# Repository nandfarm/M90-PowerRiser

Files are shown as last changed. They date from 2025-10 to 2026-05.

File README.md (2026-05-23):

# M90-PowerRiser
PowerRiser – NVMe 2230 and 2242 Expansion board for Lenovo Tiny 6 Series M90q Gen 1 and 2 and P340 and P350

# Buy preassembled boards:

Best for European locations (EUR currency): </br>


Best for International locations (USD currency): </br>


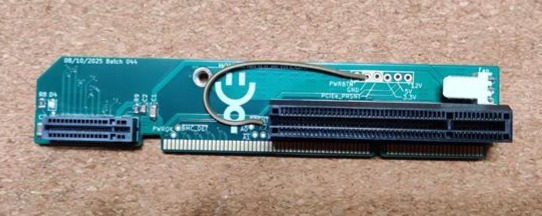
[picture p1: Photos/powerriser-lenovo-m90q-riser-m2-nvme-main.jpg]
Main photo of the board


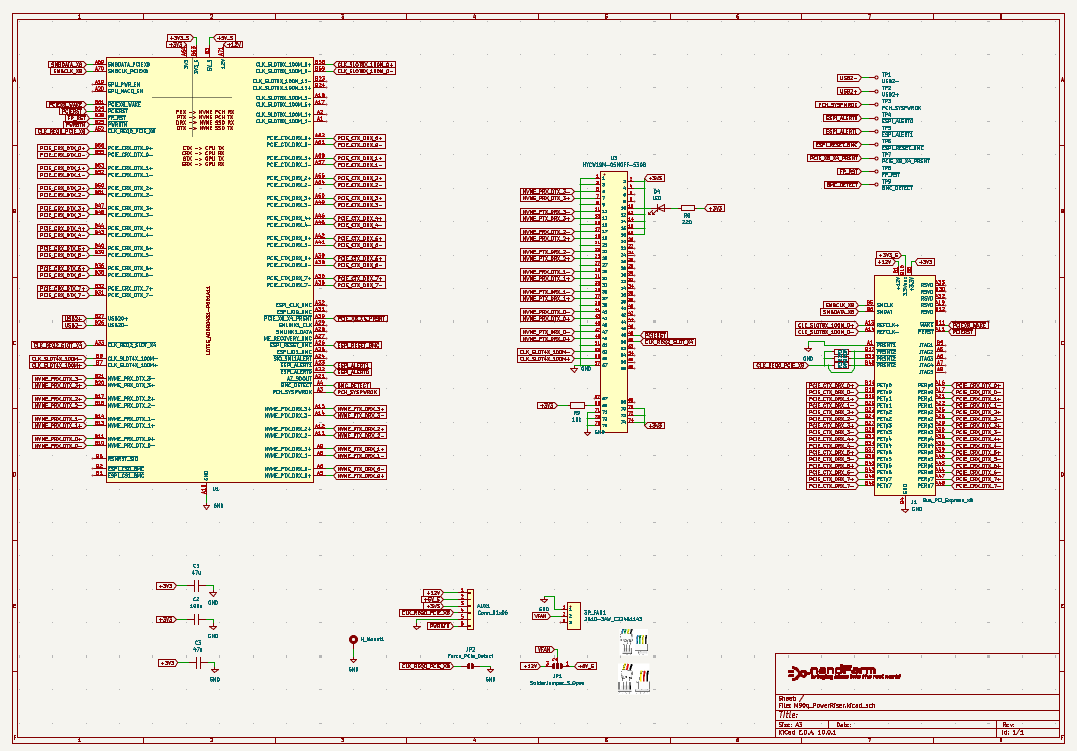
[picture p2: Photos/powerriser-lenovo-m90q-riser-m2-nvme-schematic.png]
Schematic of the board


This is the first ~UNTESTED~ TESTED version of the M90 PowerRiser. Like the previous one it is a custom-designed passive riser board that allows you to break out the proprietary Lenovo Tiny 6 series PCIe connector into a standard open-ended x8 PCIe slot, while also providing an additional M.2 NVMe slot for further storage expansion. This board was specifically designed for select Lenovo Tiny 6 series systems (10th/11th gen), such as:

- ThinkCentre M90q Gen 1 and Gen 2

- ThinkStation P340 Tiny

- ThinkStation P350 Tiny

These boards are compatible with the following Lenovo riser FRU code: 5C50W00877. Basically, this riser will do the same job and will allow you access to an extra 4-lane NVMe M.2 slot, supporting all NVMe M.2 form factors, at PCIe 3.0 speeds.

⚠ Please note: The additional M.2 slot supports only PCIe NVMe drives, not SATA drives.

## Prototype Updates (01/12/2025)

Ok some updates are required. 

The first prototype boards have arrived and I could not wait to solder one to test it. 

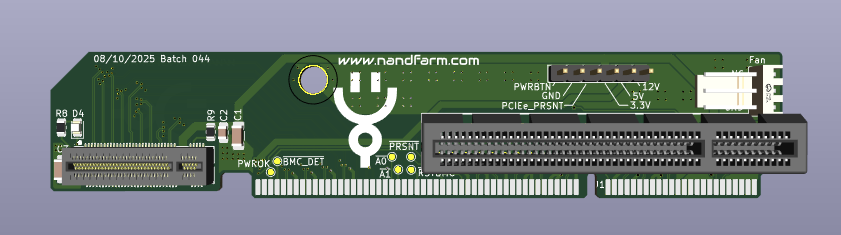
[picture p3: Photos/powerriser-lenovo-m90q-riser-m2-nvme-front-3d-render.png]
Top render of the board


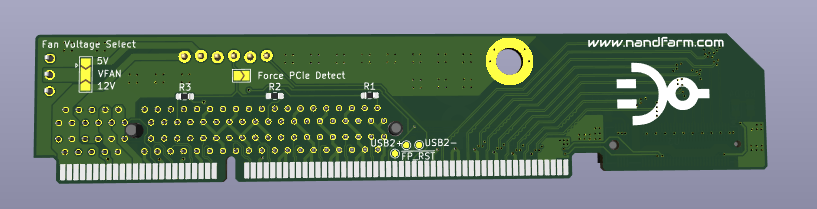
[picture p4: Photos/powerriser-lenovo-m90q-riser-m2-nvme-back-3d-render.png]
Bottom render of the board


~Issue no 1: It appears that the chassy has different folds than the m720q family of devices and the pertruding pins of the FAN connector on the bottom side of the board touch the chassy. This is a problem since no one wants a short so the fan header needs to move somewhere else or, find a surface mount version.~

Issue no 1: Has been solved by moving the connector and rotating it 180 degrees. 

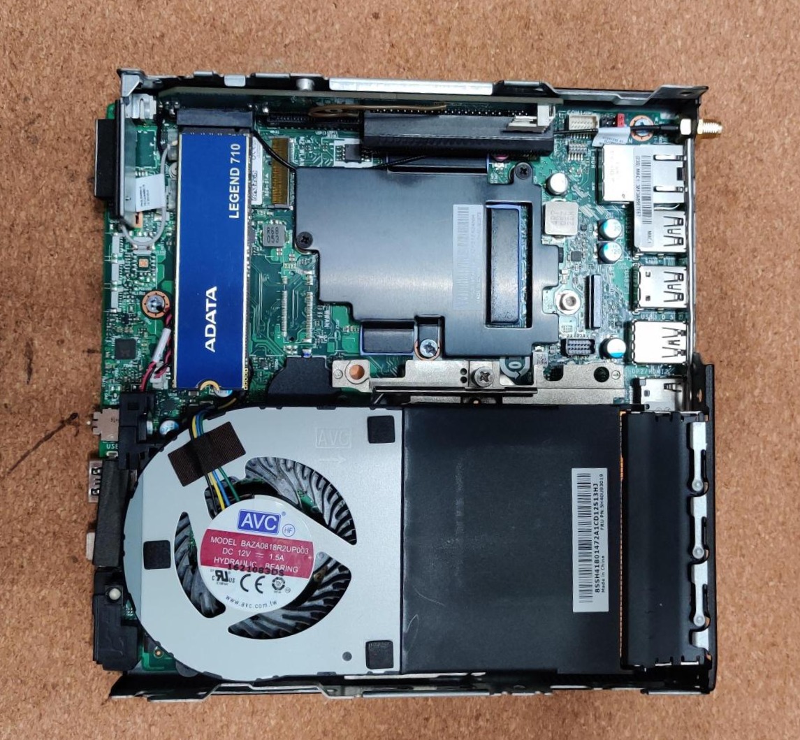
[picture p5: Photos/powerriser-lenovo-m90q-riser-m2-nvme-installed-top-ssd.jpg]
Top view of installed board


~Issue no 2: I have routed some of the low speed # detect wires poorly and the board was not initially detected by the device. After some adjustments with a box cutter and the soldering iron, the M90q detects both the PCIe PERC and the NVMe SSD. This needs to be corrected in the next hardware version.~

Issue no 2: Has been solved in the latest revision.

~Potential issue no 3: The M90q detects (lspci on Ubuntu) the NVMe but downgrades it to PCIe gen 3 (not 4) (LnkCap says PCIe4 capable and LnkSta says PCIe3 (Downgrade)). R/W speeds are matching PCIe gen 3 speeds and are stable. Not sure if the Tiny is not capable of PCIe gen 4 or there is somethign wrong with my board. The high speed trace impedances have been tested on a signal analyzer and are within spec. Did not find a way to force PCIe gen 4 speeds on the device yet. Will keep investigating.~

Potential issue no 3: Apparently this is normal behaviour as the PCH of this generation of boards is only PCIe 3.0 compatible. So the NVMe SSDs connected to this slot will run at 3.0 speeds and not at 4.0 like the ones on the motherboard. 

---------------------------------------
Other things: 

- There is no way to put the NVMe connector on the side of the riser like the m720q version of the riser since there is no space to place even the 2230 sized NVMe. The good news by putting this vertically on the riser, you can now insert 2280 sized SSDs without space constraints. The bad news is that the vertical M.2 slot can not be sourced easily/cheaply so would add an extra assembly step.
- The position of the M.2 slot is perfectly placed to clear the wifi/BT card and to have the posibility to add a longer card on the x8 PCIe slot AS LONG AS there is nothing under the PCIe board and there is no heatsink on the NVMe. (excuse the bothced fan added to the PERC card :D )
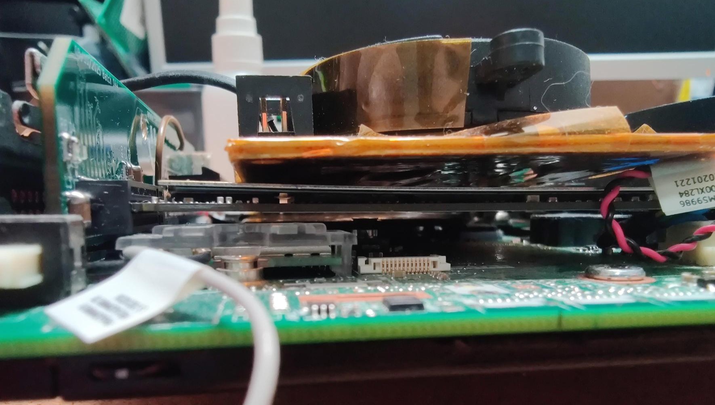
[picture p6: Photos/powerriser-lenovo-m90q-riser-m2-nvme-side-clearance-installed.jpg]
Side view of clearance of the board
  
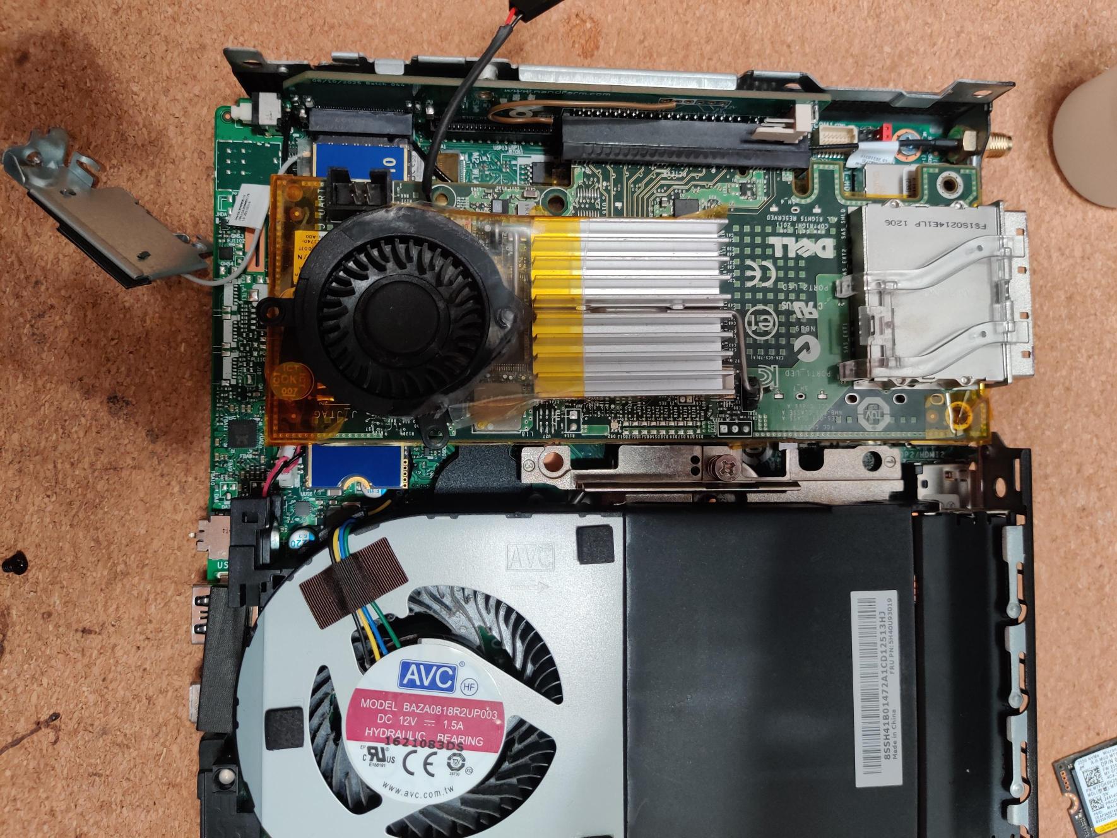
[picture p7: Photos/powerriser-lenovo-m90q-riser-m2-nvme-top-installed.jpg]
Top view of clearence of the board
  
- There seems to be a way to bifurcate the x8 connection in two x4 onnectors without any hardware modiffication on the motherboard. Have to explore this further since this could lead to the ability to connect up to 5 NVMes in one tiny device. Would be great for a NAS with RAID 5.
- 
  ↑ There is and the new board is under test. Will release once it has been thoroughly tested.
- Have to see if the USB2 port is host or device as it could be interesting for those who want to add something extra like a fan speed controller.
- 
  ↑ Will not be implemented in the current version.

I think there is value in creating this riser as it has some cool advantages: 
- you have the space for a 2280 sized SSD
- selectable fan voltage can work at 12v or 5v
- there is the posibility of bifurcation of the x8 pcie without hardware modiffications (imagine 5 NVMes on this machine -> RAID 5 NAS *drooling*)
- extra USB2 connection (not sure if device or host yet) 
- SPI connection to the PCH (have to explore this more in depth)
- no need for clock buffer/divider as the device now breaks out 4x 100MHz clock sources
- there are connections for the power and reset button that could be used if a custom chassy is made.

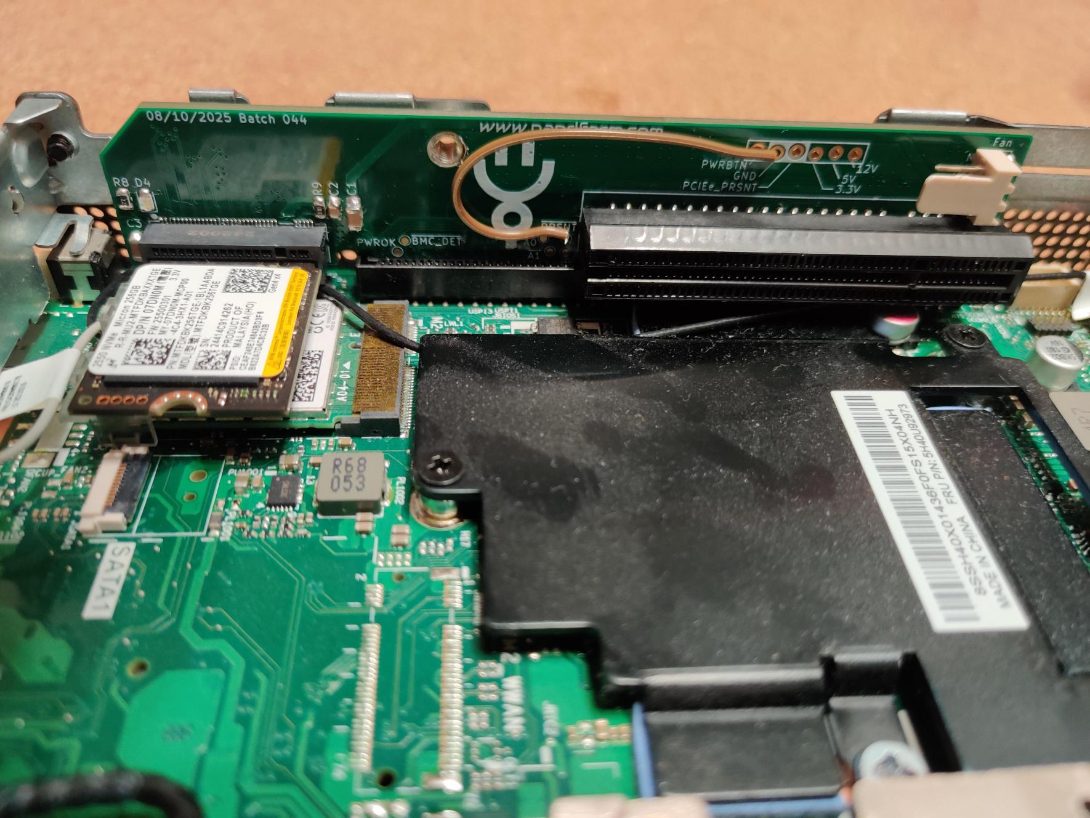
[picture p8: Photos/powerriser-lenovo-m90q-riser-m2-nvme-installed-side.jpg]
Side view of the installed board


## Usage & Limitations
You can safely install longer PCIe cards (x16), but electrically the slot remains x8.
The NVMe is no longer installed alongside the Riser board like in the Mx20 version because the proprietary Lenovo connector on the Motherboard is longer and the height does not allow it. This means that there may be interference between the NVMe and other adapters that can be inserted in the WIFI/BT port. (testing needs to be done.

NVMe drives supported: 2230, 2242 and 2260 (2280 not tested during mockup).

This riser is only compatible with the Lenovo Tiny 6 series models listed above.

SATA M.2 drives are not supported on the added M.2 slot.

The riser is capable of accepting x16 PCIe boards but in order for them to be detected, the "PCIe_Detect" solder bridge on the back needs to be bridged.

## Project Origin & Intent
This project was built from personal need, trial, and experimentation. 

## License
This project is licensed under the CERN Open Hardware License v2 - Strongly Reciprocal (CERN-OHL-S).

You are free to:

- Manufacture and assemble this board.

- Use it in your own projects.

- Modify and improve it.

However, any modifications and derived works must also be distributed under the same license and atributed.

For full license terms, please refer to [CERN-OHL-S](https://ohwr.org/project/cernohl/wikis/home).

## Disclaimer
⚠ Use at your own risk.
By using, manufacturing, or assembling this board, you accept that:

I am not responsible for any damages, whether physical, financial, or mental, arising from its use.

The design has been made available for educational, experimental, and hobbyist purposes.

Always double-check compatibility, power requirements, and mechanical fit before installation.

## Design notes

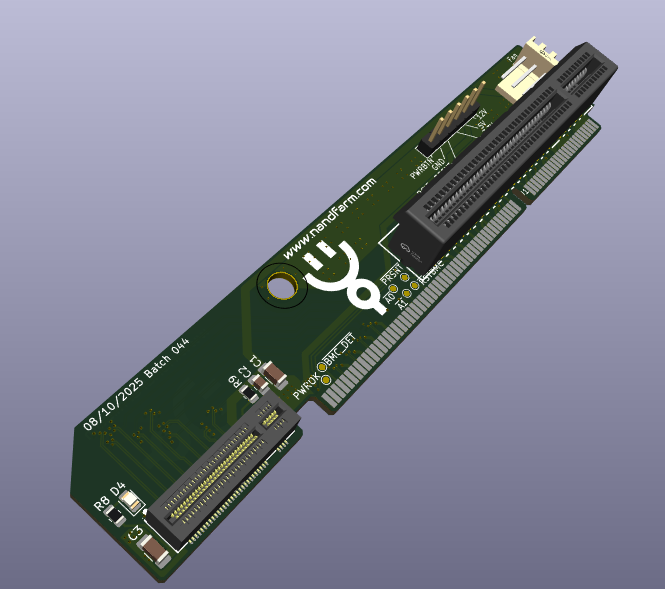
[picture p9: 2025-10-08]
Photos/powerriser-lenovo-m90q-riser-m2-nvme-side-3d-render.png

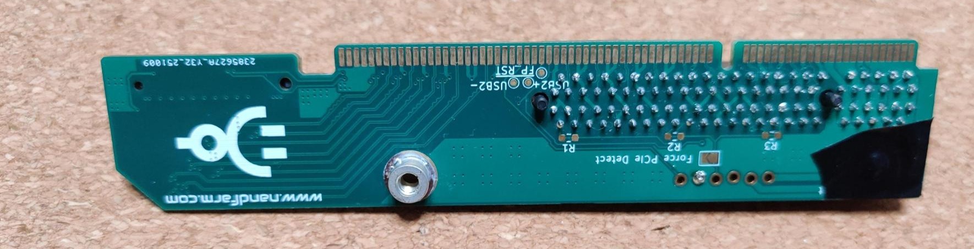
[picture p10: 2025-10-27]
Photos/powerriser-lenovo-m90q-riser-m2-nvme-back.jpg

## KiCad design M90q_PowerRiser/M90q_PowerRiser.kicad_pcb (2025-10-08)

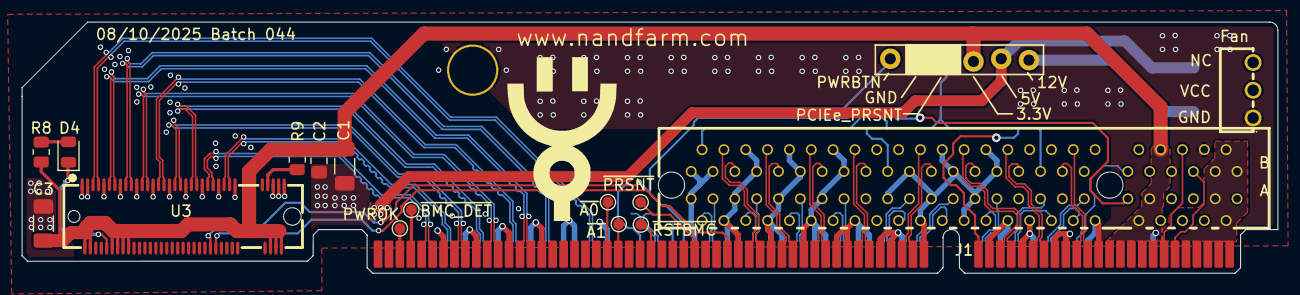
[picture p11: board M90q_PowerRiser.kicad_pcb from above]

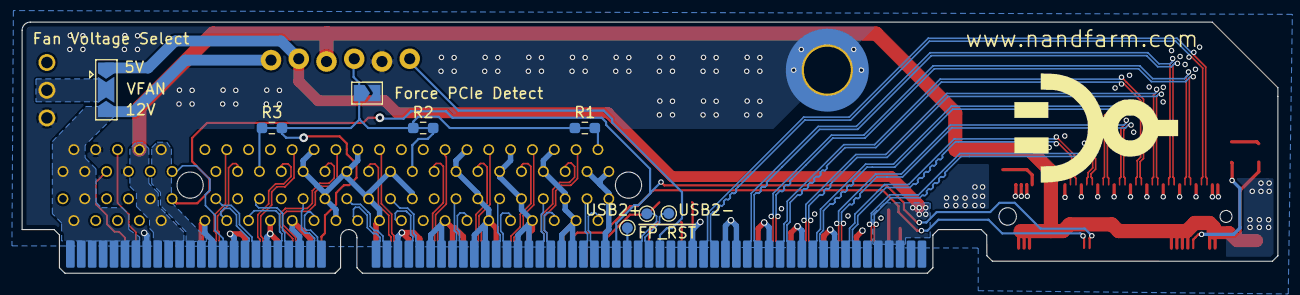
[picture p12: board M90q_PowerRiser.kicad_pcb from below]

Board: 4 copper layers, 115.0 x 23.0 mm, 26 parts (9 on the bottom side), 77 nets.

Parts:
3P_FAN1: 2510-3AW_C22451143; CONN-TH_2510-3AW
AUX1: Conn_01x06; 1x06_P2.54mm_Locking
C1, C3: 47u; C_1206_3216Metric_Pad1.33x1.80mm_HandSolder
C2: 100n; C_0805_2012Metric_Pad1.18x1.45mm_HandSolder
D4: LED; LED_0805_2012Metric
H_Mount1: MountingHole_Pad; MountingHole_4.3mm_M4_ISO7380_Pad_TopOnly
J1: Bus_PCI_Express_x8; CONN-TH_98P-P1.00-V_3183-XXXXXPXT
JP1: SolderJumper_3_Open; SolderJumper-3_P2.0mm_Open_TrianglePad1.0x1.5mm
JP2: Force_PCIe_Detect; SolderJumper-2_P1.3mm_Open_TrianglePad1.0x1.5mm
R1, R2, R3: 0R; R_0603_1608Metric_Pad0.98x0.95mm_HandSolder
R8: 220; R_0805_2012Metric
R9: 10k; R_0805_2012Metric
TP1: USB2-; TestPoint_Pad_D1.0mm
TP2: USB2+; TestPoint_Pad_D1.0mm
TP3: PWROK; TestPoint_Pad_D1.0mm
TP4: ~{A0}; TestPoint_Pad_D1.0mm
TP5: ~{A1}; TestPoint_Pad_D1.0mm
TP6: ~{RSTBMC}; TestPoint_Pad_D1.0mm
TP7: ~{PRSNT}; TestPoint_Pad_D1.0mm
TP8: ~{FP_RST}; TestPoint_Pad_D1.0mm
TP9: ~{BMC_DET}; TestPoint_Pad_D1.0mm
U1: M90q_PCIe
U3: HYCW19M-05NGFF-530B; CONN-SMD_HYCW19M-05NGFF-530B

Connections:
+3V3: AUX1.3, C1.1, C2.1, C3.1, J1.A9 (+3.3V), J1.A10 (+3.3V), J1.B8 (+3.3V), R8.2, R9.1, U1.A64 (3V3), U1.A65 (3V3), U1.A66 (3V3), U1.A67 (3V3), U1.A68 (3V3), U1.B65 (3V3), U1.B66 (3V3), U1.B67 (3V3), U3.2, U3.4, U3.12, U3.14, U3.16, U3.18, U3.70, U3.72, U3.74
+3V3_S: J1.B10 (3.3Vaux), U1.B63 (3V3_S), U1.B64 (3V3_S)
+5V_S: AUX1.2, JP1.1 (A), U1.B3 (5V_S), U1.B4 (5V_S), U1.B5 (5V_S)
+12V: AUX1.1, J1.A2 (+12V), J1.A3 (+12V), J1.B1 (+12V), J1.B2 (+12V), J1.B3 (+12V), JP1.3 (B), U1.A71 (12V), U1.A72 (12V), U1.A73 (12V), U1.A74 (12V), U1.A75 (12V), U1.B69 (12V), U1.B70 (12V), U1.B71 (12V), U1.B72 (12V), U1.B73 (12V), U1.B74 (12V), U1.B75 (12V)
CLK_SLOT4X_100M+: U1.B7 (CLK_SLOT4X_100M+), U3.55
CLK_SLOT4X_100M-: U1.B8 (CLK_SLOT4X_100M-), U3.53
CLK_SLOT8X_100M_0+: J1.A13 (REFCLK+), U1.B58 (CLK_SLOT8X_100M_0+)
CLK_SLOT8X_100M_0-: J1.A14 (REFCLK-), U1.B59 (CLK_SLOT8X_100M_0-)
GND: 3P_FAN1.1, AUX1.5, C1.2, C2.2, C3.2, H_Mount1.1, J1.A1 (~PRSNT1), J1.A4 (GND), J1.A12 (GND), J1.A15 (GND), J1.A18 (GND), J1.A20 (GND), J1.A23 (GND), J1.A24 (GND), J1.A27 (GND), J1.A28 (GND), J1.A31 (GND), J1.A34 (GND), J1.A37 (GND), J1.A38 (GND), J1.A41 (GND), J1.A42 (GND), J1.A45 (GND), J1.A46 (GND), J1.A49 (GND), J1.B4 (GND), J1.B7 (GND), J1.B13 (GND), J1.B16 (GND), J1.B18 (GND), J1.B21 (GND), J1.B22 (GND), J1.B25 (GND), J1.B26 (GND), J1.B29 (GND), J1.B32 (GND), J1.B35 (GND), J1.B36 (GND), J1.B39 (GND), J1.B40 (GND), J1.B43 (GND), J1.B44 (GND), J1.B47 (GND), J1.B49 (GND), JP2.2 (B), U1.A7 (GND), U1.A10 (GND), U1.A13 (GND), U1.A16 (GND), U1.A34 (GND), U1.A37 (GND), U1.A40 (GND), U1.A43 (GND), U1.A44 (GND), U1.A47 (GND), U1.A48 (GND), U1.A51 (GND), U1.A53 (GND), U1.A56 (GND), U1.A59 (GND), U1.A60 (GND), U1.A63 (GND), U1.B9 (GND), U1.B12 (GND), U1.B15 (GND), U1.B18 (GND), U1.B19 (GND), U1.B22 (GND), U1.B30 (GND), U1.B33 (GND), U1.B34 (GND), U1.B37 (GND), U1.B38 (GND), U1.B41 (GND), U1.B42 (GND), U1.B45 (GND), U1.B46 (GND), U1.B49 (GND), U1.B54 (GND), U1.B57 (GND), U1.B60 (GND), U1.B62 (GND), U1.B68 (GND), U3.1, U3.3, U3.9, U3.15, U3.21, U3.27, U3.33, U3.39, U3.45, U3.51, U3.57, U3.71, U3.73, U3.75
NVME_PRX_DTX_0+: U1.B11 (NVME_PRX_DTX_0+), U3.43
NVME_PRX_DTX_0-: U1.B10 (NVME_PRX_DTX_0-), U3.41
NVME_PRX_DTX_1+: U1.B13 (NVME_PRX_DTX_1+), U3.31
NVME_PRX_DTX_1-: U1.B14 (NVME_PRX_DTX_1-), U3.29
NVME_PRX_DTX_2+: U1.B17 (NVME_PRX_DTX_2+), U3.19
NVME_PRX_DTX_2-: U1.B16 (NVME_PRX_DTX_2-), U3.17
NVME_PRX_DTX_3+: U1.B20 (NVME_PRX_DTX_3+), U3.7
NVME_PRX_DTX_3-: U1.B21 (NVME_PRX_DTX_3-), U3.5
NVME_PTX_DRX_0+: U1.A5 (NVME_PTX_DRX_0+), U3.49
NVME_PTX_DRX_0-: U1.A6 (NVME_PTX_DRX_0-), U3.47
NVME_PTX_DRX_1+: U1.A9 (NVME_PTX_DRX_1+), U3.37
NVME_PTX_DRX_1-: U1.A8 (NVME_PTX_DRX_1-), U3.35
NVME_PTX_DRX_2+: U1.A12 (NVME_PTX_DRX_2+), U3.25
NVME_PTX_DRX_2-: U1.A11 (NVME_PTX_DRX_2-), U3.23
NVME_PTX_DRX_3+: U1.A15 (NVME_PTX_DRX_3+), U3.13
NVME_PTX_DRX_3-: U1.A14 (NVME_PTX_DRX_3-), U3.11
unnamed: D4.2 (A), R8.1
unnamed: D4.1 (K), U3.10
unnamed: R9.2, U3.69
PCH_SYSPWROK: TP3.1, U1.A3 (PCH_SYSPWROK)
PCIE_CRX_DTX_0+: J1.A16 (PERp0), U1.B56 (PCIE_CRX_DTX_0+)
PCIE_CRX_DTX_0-: J1.A17 (PERn0), U1.B55 (PCIE_CRX_DTX_0-)
PCIE_CRX_DTX_1+: J1.A21 (PERp1), U1.B53 (PCIE_CRX_DTX_1+)
PCIE_CRX_DTX_1-: J1.A22 (PERn1), U1.B52 (PCIE_CRX_DTX_1-)
PCIE_CRX_DTX_2+: J1.A25 (PERp2), U1.B50 (PCIE_CRX_DTX_2+)
PCIE_CRX_DTX_2-: J1.A26 (PERn2), U1.B51 (PCIE_CRX_DTX_2-)
PCIE_CRX_DTX_3+: J1.A29 (PERp3), U1.B47 (PCIE_CRX_DTX_3+)
PCIE_CRX_DTX_3-: J1.A30 (PERn3), U1.B48 (PCIE_CRX_DTX_3-)
PCIE_CRX_DTX_4+: J1.A35 (PERp4), U1.B44 (PCIE_CRX_DTX_4+)
PCIE_CRX_DTX_4-: J1.A36 (PERn4), U1.B43 (PCIE_CRX_DTX_4-)
PCIE_CRX_DTX_5+: J1.A39 (PERp5), U1.B40 (PCIE_CRX_DTX_5+)
PCIE_CRX_DTX_5-: J1.A40 (PERn5), U1.B39 (PCIE_CRX_DTX_5-)
PCIE_CRX_DTX_6+: J1.A43 (PERp6), U1.B36 (PCIE_CRX_DTX_6+)
PCIE_CRX_DTX_6-: J1.A44 (PERn6), U1.B35 (PCIE_CRX_DTX_6-)
PCIE_CRX_DTX_7+: J1.A47 (PERp7), U1.B32 (PCIE_CRX_DTX_7+)
PCIE_CRX_DTX_7-: J1.A48 (PERn7), U1.B31 (PCIE_CRX_DTX_7-)
PCIE_CTX_DRX_0+: J1.B14 (PETp0), U1.A62 (PCIE_CTX_DRX_0+)
PCIE_CTX_DRX_0-: J1.B15 (PETn0), U1.A61 (PCIE_CTX_DRX_0-)
PCIE_CTX_DRX_1+: J1.B19 (PETp1), U1.A58 (PCIE_CTX_DRX_1+)
PCIE_CTX_DRX_1-: J1.B20 (PETn1), U1.A57 (PCIE_CTX_DRX_1-)
PCIE_CTX_DRX_2+: J1.B23 (PETp2), U1.A55 (PCIE_CTX_DRX_2+)
PCIE_CTX_DRX_2-: J1.B24 (PETn2), U1.A54 (PCIE_CTX_DRX_2-)
PCIE_CTX_DRX_3+: J1.B27 (PETp3), U1.A50 (PCIE_CTX_DRX_3+)
PCIE_CTX_DRX_3-: J1.B28 (PETn3), U1.A49 (PCIE_CTX_DRX_3-)
PCIE_CTX_DRX_4+: J1.B33 (PETp4), U1.A46 (PCIE_CTX_DRX_4+)
PCIE_CTX_DRX_4-: J1.B34 (PETn4), U1.A45 (PCIE_CTX_DRX_4-)
PCIE_CTX_DRX_5+: J1.B37 (PETp5), U1.A42 (PCIE_CTX_DRX_5+)
PCIE_CTX_DRX_5-: J1.B38 (PETn5), U1.A41 (PCIE_CTX_DRX_5-)
PCIE_CTX_DRX_6+: J1.B41 (PETp6), U1.A39 (PCIE_CTX_DRX_6+)
PCIE_CTX_DRX_6-: J1.B42 (PETn6), U1.A38 (PCIE_CTX_DRX_6-)
PCIE_CTX_DRX_7+: J1.B45 (PETp7), U1.A36 (PCIE_CTX_DRX_7+)
PCIE_CTX_DRX_7-: J1.B46 (PETn7), U1.A35 (PCIE_CTX_DRX_7-)
SMBCLK_X8: J1.B5 (SMCLK), U1.A70 (SMBCLK_PCIEX8)
SMBDATA_X8: J1.B6 (SMDAT), U1.A69 (SMBDATA_PCIEX8)
USB2+: TP2.1, U1.B27 (USB20+)
USB2-: TP1.1, U1.B26 (USB20-)
VFAN: 3P_FAN1.2, JP1.2 (C)
~BMC_DETECT: TP9.1, U1.A4 (~BMC_DETECT)
~CLK_REQ0_PCIE_X8: AUX1.4, J1.B17 (~PRSNT2), J1.B31 (~PRSNT2), J1.B48 (~PRSNT2), JP2.1 (A), R1.1, R1.2, R2.1, R2.2, R3.1, R3.2, U1.A52 (~CLK_REQ0_PCIE_X8)
~CLK_REQ2_SLOT_X4: U1.A33 (~CLK_REQ2_SLOT_X4), U3.50
~ESPI_ALERT0: TP4.1, U1.A22 (~ESPI_ALERT0)
~ESPI_ALERT1: TP5.1, U1.A23 (~ESPI_ALERT1)
~ESPI_RESET_BMC: TP6.1, U1.A26 (~ESPI_RESET_BMC)
~FP_RST: TP8.1, U1.B28 (~FP_RST)
~PCIERST: J1.A11 (~PERST), U1.B29 (~PCIERST), U3.48
~PCIEX8_WAKE: J1.B11 (~WAKE), U1.B61 (~PCIEX8_WAKE)
~PCIE_X8_X4_PRSNT: TP7.1, U1.A30 (~PCIE_X8_X4_PRSNT)
~PWRBTN: AUX1.6, U1.B25 (~PWRBTN)

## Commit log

2025-10-08 Initial upload
    [M90q_PowerRiser.kicad_pcb, M90q_PowerRiser.kicad_sch]
2025-10-27 more photos of the first version of the prototype
2025-10-27 Document prototype updates and testing issues
    Added prototype updates and issues encountered during testing.
2025-10-27 Update README with board images and NVMe info
    Added images of the board and clarified NVMe installation details.
2025-12-06 Revise prototype updates and issue resolutions
    Updated prototype issues and resolutions in README.
2025-12-06 Change version status from UNTESTED to TESTED
    Updated the README to reflect the version status of the M90 PowerRiser.
2026-05-23 Update README with purchasing options for boards
    Added links for purchasing preassembled boards for European and International customers.
